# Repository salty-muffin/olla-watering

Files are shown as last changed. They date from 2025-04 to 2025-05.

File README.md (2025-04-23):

# olla-watering
automatic olla filling with a rp pico, valves &amp; sensors

# plan

JSON on every Pico that contains: 
- time slot, when the watering program shall be started
- maximum filling for each valve
- overfill time in seconds (time the valve stays open after the sensor registers `full`)

# filling program
For each Valve 
- average sensor signal over X seconds (long) to estimate if the olla really needs filling
- after valve is opened, a shorter peridod of time is used to estimate the new `full` state
- then the valve stays open for X seconds, as set in the JSON to ensure the sensor will not register an empty olla too soon.

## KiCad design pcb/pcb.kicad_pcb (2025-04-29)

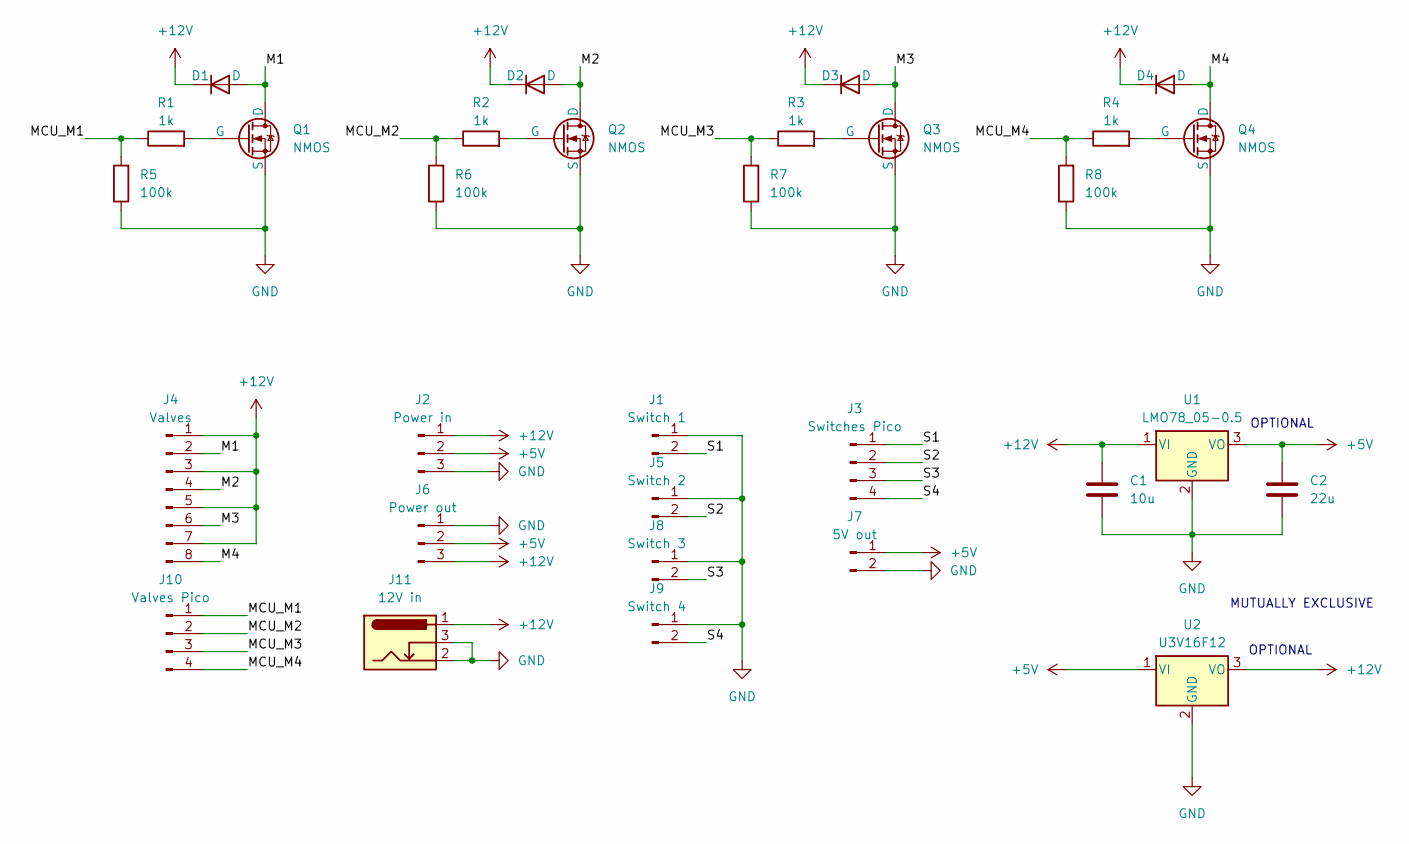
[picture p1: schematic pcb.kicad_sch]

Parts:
C1: 10u; C_1206_3216Metric_Pad1.33x1.80mm_HandSolder
C2: 22u; C_1206_3216Metric_Pad1.33x1.80mm_HandSolder
D1, D2, D3, D4: D; D_DO-41_SOD81_P10.16mm_Horizontal
J1: Switch 1; PinHeader_1x02_P2.54mm_Vertical
J2: Power in; TerminalBlock_4Ucon_1x03_P3.50mm_Horizontal
J3: Switches Pico; PinHeader_1x04_P2.54mm_Vertical
J4: Valves; JST_XH_B8B-XH-A_1x08_P2.50mm_Vertical
J5: Switch 2; PinHeader_1x02_P2.54mm_Vertical
J6: Power out; TerminalBlock_4Ucon_1x03_P3.50mm_Horizontal
J7: 5V out; PinHeader_1x02_P2.54mm_Vertical
J8: Switch 3; PinHeader_1x02_P2.54mm_Vertical
J9: Switch 4; PinHeader_1x02_P2.54mm_Vertical
J10: Valves Pico; PinHeader_1x04_P2.54mm_Vertical
J11: 12V in; BarrelJack_Wuerth_6941xx301002
Q1, Q2, Q3, Q4: NMOS; TO-220-3_Vertical_olla
R1, R2, R3, R4: 1k; R_Axial_DIN0207_L6.3mm_D2.5mm_P7.62mm_Horizontal
R5, R6, R7, R8: 100k; R_Axial_DIN0207_L6.3mm_D2.5mm_P7.62mm_Horizontal
U1: LMO78_05-0.5
U2: U3V16F12

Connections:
+5V: C2.1, J2.2, J6.2, J7.1, U1.3 (VO), U2.1 (VI)
+12V: C1.1, D1.1 (K), D2.1 (K), D3.1 (K), D4.1 (K), J2.1, J4.1, J4.3, J4.5, J4.7, J6.3, J11.1, U1.1 (VI), U2.3 (VO)
/M1: D1.2 (A), J4.2, Q1.1 (D)
/M2: D2.2 (A), J4.4, Q2.1 (D)
/M3: D3.2 (A), J4.6, Q3.1 (D)
/M4: D4.2 (A), J4.8, Q4.1 (D)
/MCU_M1: J10.1, R1.1, R5.2
/MCU_M2: J10.2, R2.1, R6.2
/MCU_M3: J10.3, R3.1, R7.2
/MCU_M4: J10.4, R4.1, R8.2
/S1: J1.2, J3.1
/S2: J3.2, J5.2
/S3: J3.3, J8.2
/S4: J3.4, J9.2
GND: C1.2, C2.2, J1.1, J2.3, J5.1, J6.1, J7.2, J8.1, J9.1, J11.2, J11.3, Q1.3 (S), Q2.3 (S), Q3.3 (S), Q4.3 (S), R5.1, R6.1, R7.1, R8.1, U1.2 (GND), U2.2 (GND)
unnamed: Q1.2 (G), R1.2
unnamed: Q2.2 (G), R2.2
unnamed: Q3.2 (G), R3.2
unnamed: Q4.2 (G), R4.2

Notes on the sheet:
OPTIONAL
MUTUALLY EXCLUSIVE

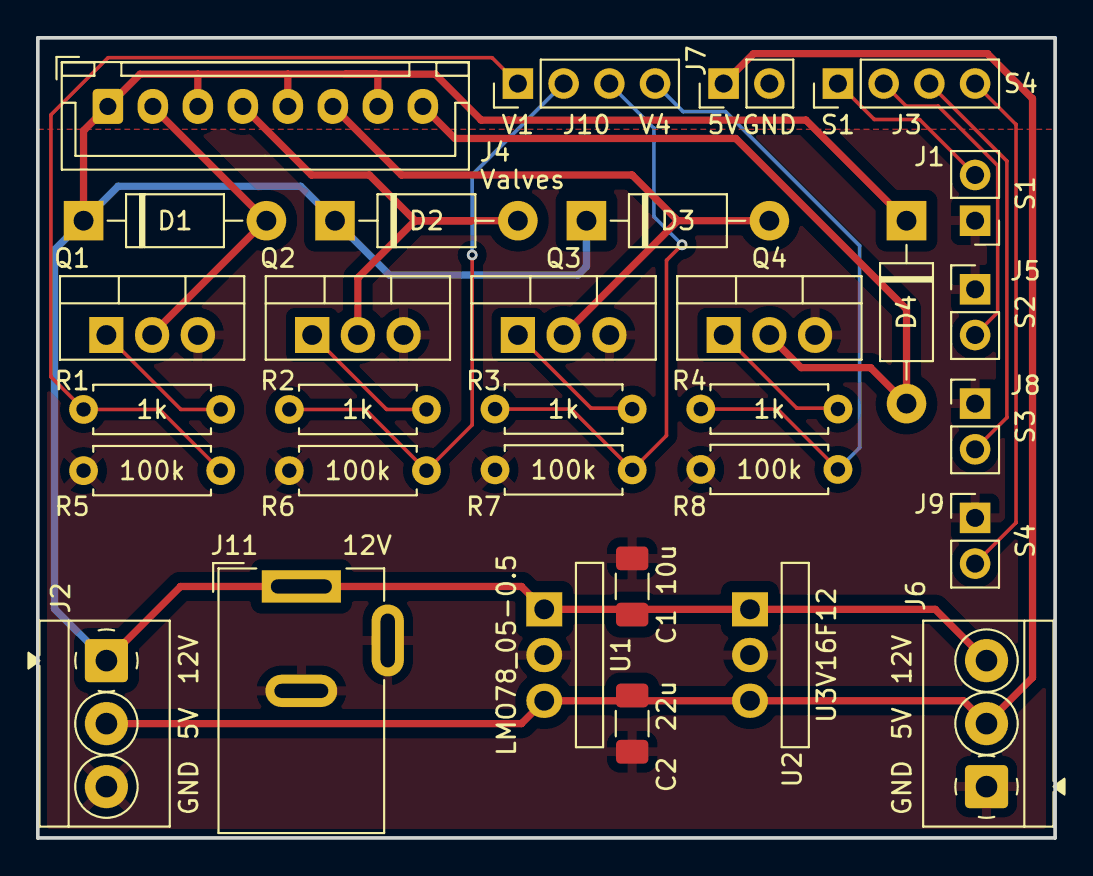
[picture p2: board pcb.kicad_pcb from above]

Board: 2 copper layers, 56.5 x 44.4 mm, 31 parts (0 on the bottom side), 19 nets.

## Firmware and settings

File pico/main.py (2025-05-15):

import json
from swimmer import Swimmer
import time
from machine import Pin, RTC, Timer
import machine

VALVE_PINS = [9, 8, 7, 6]
SWIMMER_PINS = [5, 4, 3, 2]


def main():
    # Underclock the cpu
    machine.freq(48_000_000)
    print(f"CPU runs at {machine.freq()}Hz")

    # Setup
    led = Pin("LED", Pin.OUT)

    # Initialize timer for error blinking
    timer = Timer(-1)

    # Initialize RTC
    rtc = RTC()
    rtc.datetime((2025, 5, 1, 0, 0, 0, 0, 0))
    print(f"Time initialized: {rtc.datetime()}")

    def print_timestamp(*values) -> None:
        print(
            f"[{get_datetime_string(rtc.datetime())}]",
            *values,
        )

    def log_error(error: str, error_file="errors.log"):
        with open(error_file, "a") as file:
            file.write(f"[{get_datetime_string(rtc.datetime())}] {error}\n")

    # Open and read the JSON file
    print("Importing settings")
    try:
        with open("settings.json", "r") as file:
            settings = json.load(file)
        for key, value in settings.items():
            print(f"{key}: {value}")
    except (OSError, ValueError) as e:
        print(f"Error loading settings: {e}")
        log_error(str(e))
        error_blinking(led, timer)

    # Initialize swimmers & valves
    swimmers = [Swimmer(pin) for pin in SWIMMER_PINS]
    valves = [Pin(n, Pin.OUT) for n in VALVE_PINS]

    for valve in valves:
        valve.off()

    # Copy Settings for easier readability
    overfill_times_s = settings["overfill_time_per_valve_seconds"]
    max_fill_time_s = settings["max_fill_time_per_valve_seconds"]
    interval_ms = settings["interval_ms"]
    samples_empty = settings["samples_empty"]
    samples_full = settings["samples_full"]
    time_shift_h = settings["time_shift_hours"]
    time_slot_length_h = settings["time_slot_length_hours"]
    threshold = settings["threshold"]

    def fill_sensor_stack() -> None:
        led.on()
        starting_time = time.ticks_ms()
        full_cycle = interval_ms * max(samples_empty, samples_full)
        print_timestamp(f"Initializing sensor data stack for {full_cycle / 1000}s...")
        while time.ticks_diff(time.ticks_ms(), starting_time) < full_cycle:
            for swimmer in swimmers:
                swimmer.update()
            time.sleep_ms(10)
        led.off()

    try:
        # Loop
        sequence_index = len(swimmers) + 1
        filling = False
        overfilling = False
        time_slot = False
        starting_time = time.ticks_ms()
        while True:
            # Start the sequence only at the beginning of the timeslot
            if check_time_slot(time_shift_h, time_slot_length_h, rtc.datetime()):
                if not time_slot:
                    print_timestamp("Time slot is now, starting watering program...")
                    sequence_index = 0
                    time_slot = True

                    # Fill sensor data one full time
                    led.on()
                    fill_sensor_stack()
                    led.off()
            else:
                if time_slot:
                    time_slot = False

            # Fill ollas if in sequence
            if sequence_index < len(swimmers):
                # Update all swimmers
                updated = any([swimmer.update() for swimmer in swimmers])

                # If there was an update, evaluate switches and valves
                if updated:
                    try:
                        if not overfilling:
                            # Fill the current olla if it is empty
                            if (
                                not filling
                                and swimmers[sequence_index].empty() < threshold
                            ):
                                print_timestamp(
                                    f"Olla {sequence_index} is empty, start filling valve at pin {VALVE_PINS[sequence_index]} for max {max_fill_time_s[sequence_index]}s..."
                                )
                                valves[sequence_index].on()
                                filling = True
                                starting_time = time.ticks_ms()
                            # Skip it if it is still full
                            elif (
                                not filling
                                and swimmers[sequence_index].full() >= threshold
                            ):
                                print_timestamp(f"Olla {sequence_index} is full")
                                sequence_index += 1
                            # Stop filling if it has been filled
                            elif (
                                filling and swimmers[sequence_index].full() >= threshold
                            ):
                                print_timestamp(
                                    f"Filled olla {sequence_index} in {time.ticks_diff(time.ticks_ms(), starting_time) / 1000}s"
                                )
                                print_timestamp(
                                    f"Now topping off for {overfill_times_s[sequence_index]}s"
                                )
                                filling = False
                                overfilling = True
                                starting_time = time.ticks_ms()
                            # or the maximum fill time has been reached
                            elif (
                                filling
                                and time.ticks_diff(time.ticks_ms(), starting_time)
                                / 1000
                                >= max_fill_time_s[sequence_index]
                            ):
                                print_timestamp(
                                    f"Filled olla {sequence_index} for the max fill time of {max_fill_time_s[sequence_index]}s"
                                )
                                valves[sequence_index].off()
                                filling = False
                                log_error(
                                    f"Stopped filling olla {sequence_index} due to max fill time"
                                )
                                sequence_index += 1
                                error_blinking(led, timer, blocking=False)

                        # After filling, possibly top it off a bit longer
                        elif (
                            time.ticks_diff(time.ticks_ms(), starting_time) / 1000
                            >= overfill_times_s[sequence_index]
                        ):
                            print_timestamp(
                                f"Topped off olla {sequence_index} in {time.ticks_diff(time.ticks_ms(), starting_time) / 1000}s"
                            )
                            valves[sequence_index].off()
                            overfilling = False
                            sequence_index += 1
                    except Exception as e:
                        print_timestamp(f"Error filling ollas: {e}")
                        for valve in valves:
                            valve.off()
                        log_error(str(e))
                        error_blinking(led, timer, blocking=False)

            # Shut all valves if sequence is over as a precaution
            if sequence_index == len(swimmers):
                print_timestamp(
                    "All ollas have been checked and are full, ending watering program for today"
                )
                for valve in valves:
                    valve.off()
                sequence_index += 1

            # Sleep a little bit in every loop to keep the cpu chill
            time.sleep_ms(10)
    except KeyboardInterrupt:
        print("Exiting...")
        for valve in valves:
            valve.off()
        raise SystemExit


def check_time_slot(
    time_shift_hours: float, time_slot_length_hours: float, now: tuple
) -> bool:
    """
    Check if the current time falls within a specified time slot.

    Args:
        time_shift_hours (float): The start hour of the time slot (offset from 0).
        time_slot_length_hours (float): The duration of the time slot in hours.
        now (tuple): A time tuple where the 5th element (index 4) represents the current hour.

    Returns:
        bool: True if the current time is within the time slot, False otherwise.
    """
    return time_shift_hours <= now[4] < time_slot_length_hours + time_shift_hours
    # return not bool(now[4] % 2)


def error_blinking(led: Pin, timer: Timer, blocking=True) -> None:
    """
    Blinks the LED.

    Args:
        blocking (boolean): Should the blinking occur in the background
    """

    def tick(timer):
        led.toggle()

    timer.init(freq=1, mode=Timer.PERIODIC, callback=tick)

    if blocking:
        while True:
            time.sleep(1)


def log_error(error: str, error_file="errors.log"):
    with open(error_file, "a") as file:
        file.write(f"[{time.ticks_ms() / 1000}] {error}\n")


def zfl(s, width):
    # Pads the provided string with leading 0's to suit the specified 'chrs' length
    # Force # characters, fill with leading 0's
    return "{:0>{w}}".format(s, w=width)


def get_datetime_string(dt: tuple) -> str:
    year = zfl(str(dt[0]), 4)
    month = zfl(str(dt[1]), 2)
    day = zfl(str(dt[2]), 2)
    hour = zfl(str(dt[4]), 2)
    minute = zfl(str(dt[5]), 2)
    second = zfl(str(dt[6]), 2)

    return f"{year}/{month}/{day} {hour}:{minute}:{second}"


if __name__ == "__main__":
    main()

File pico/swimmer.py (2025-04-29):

from machine import Pin
import time


def mean(l: list[float]) -> float:
    return sum(l) / len(l)


class Swimmer:
    """
    A class for water level detection using a floating sensor connected to a GPIO pin.

    The Swimmer monitors water levels by sampling a sensor at regular intervals.

    Attributes:
        pin_number (int): GPIO pin number where the sensor is connected
        interval_ms (int): Sampling interval in milliseconds
        samples_empty (int): Number of samples to consider when checking if empty
        samples_full (int): Number of samples to consider when checking if full
    """

    def __init__(
        self,
        pin_number: int,
        interval_ms=100,
        samples_empty=200,
        samples_full=20,
    ) -> None:
        self._pin = Pin(pin_number, Pin.IN, Pin.PULL_UP)
        self._interval = interval_ms
        self._samples_empty = samples_empty
        self._samples_full = samples_full

        # Initialize sample buffer with zeros
        self._samples = [0.0] * max(self._samples_empty, self._samples_full)
        self._last_sample_time = time.ticks_ms()
        self._average = 0.0

    def update(self) -> bool:
        """
        Take a new sensor reading if the sampling interval has elapsed.

        This method should be called frequently in the main loop.

        Returns:
            bool: True if a new sample was taken, False otherwise
        """
        current_time = time.ticks_ms()
        if time.ticks_diff(current_time, self._last_sample_time) >= self._interval:
            # Remove oldest sample
            self._samples.pop(0)

            # Add new sample (sensor reading)
            self._samples.append(float(self._pin.value()))

            return True
        return False

    def empty(self) -> float:
        """
        Return the mean of the samples to check if the container is empty.

        Returns:
            float: mean of recent samples considered to check if empty
        """
        return mean(self._samples[-self._samples_empty : -1])

    def full(self) -> float:
        """
        Return the mean of the samples to check if the container is full.

        Returns:
            float: mean of recent samples considered to check if full
        """
        return mean(self._samples[-self._samples_full : -1])

    def reset(self) -> None:
        """
        Reset the state of the sensor.

        Returns:
            None
        """
        self._samples = [0.0] * max(self._samples_empty, self._samples_full)

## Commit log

2025-03-07 first pcb design
    [pcb.kicad_pcb, pcb.kicad_sch]
2025-03-07 finished board
    [pcb.kicad_pcb]
2025-04-23 refactor: update switch condition to improve readability
2025-04-23 feat: implement Swimmer class for water level detection with sensor readings
2025-04-23 feat: add Pin class for GPIO control with on/off methods as a dummy
2025-04-23 feat: add reset method to Swimmer class for state management
    [swimmer.py]
2025-04-23 Fix time slot check and improve swimmer sensor logic; refactor mean calculation in Swimmer class
    [main.py, swimmer.py]
2025-04-29 finalized pcb design
    [pcb-B_Cu.gbl, pcb-B_Mask.gbs, pcb-B_Paste.gbp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]
2025-04-29 first error free version (so far)
    [main.py, swimmer.py]
2025-04-30 fixed fatal error: valves not closing when stopping due to max fill time reached
    [main.py]
2025-05-01 update settings.json to increase max fill time and reduce overfill time per valve
2025-05-06 reduced cpu frequency and implemented lightsleep to reduce power consumtion
2025-05-09 Revert "Merge pull request #2 from salty-muffin/less-power"
    This reverts commit d77fe27bbbebd9265bdda4816e5cc27d5ede3d6a, reversing
    changes made to bab276253b1ad47a92121fc09bd17e3b1b6c4d56.
    [main.py]
2025-05-09 Revert "Refactor main.py to improve logging and RTC initialization; added timestamped logging and removed redundant code."
    This reverts commit b4701d842b13b28ac4a88064fd5fc5d61f346008.
    [main.py]
2025-05-15 Fix: started with a higher sequence index to avoid wrong starting message
    [main.py]
2025-05-15 Refactor main.py to encapsulate fill sensor logic in a dedicated function and improve readability.
2025-05-15 Only checking sensors now, when in sequence
